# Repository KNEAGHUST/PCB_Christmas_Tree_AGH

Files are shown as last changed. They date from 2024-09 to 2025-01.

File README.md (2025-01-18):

<p align="center">PCB_Christmas_Tree_AGH</p>

<h2>🧐 Features</h2>

So... it's a christmas tree... just made from a PCB!

It is green, has stars on it and... it blinks!

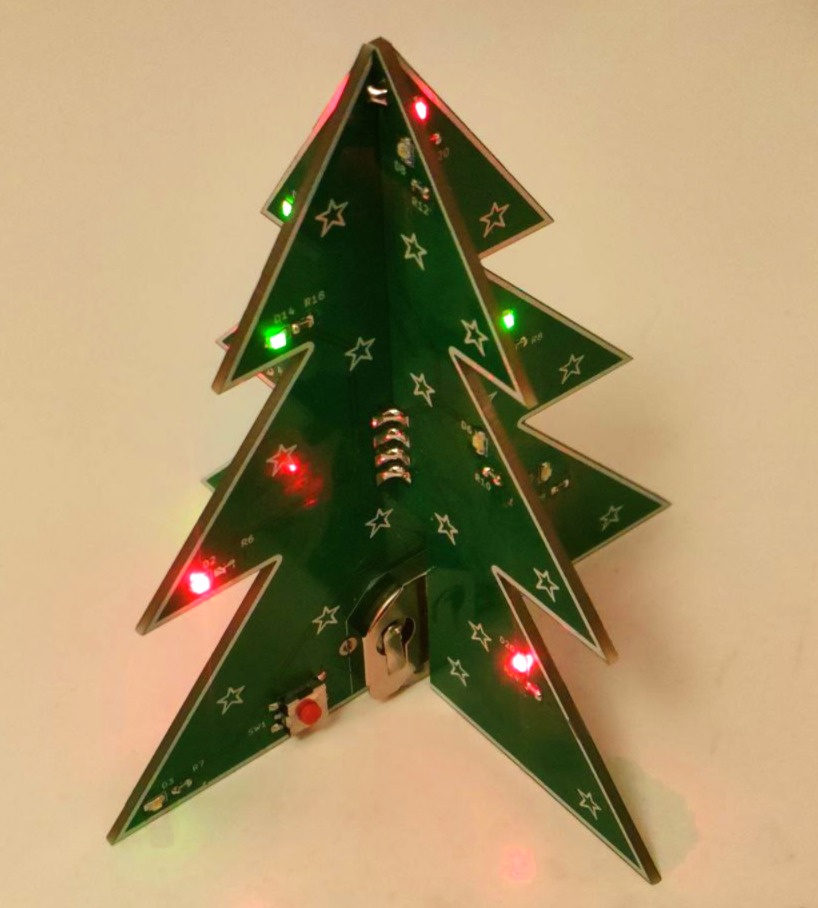
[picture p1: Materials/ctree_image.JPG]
ctree photo


<h2>💾 PCB Design</h2>

The schematics and PCB were designed using KiCAD 7. All the files are available in this repository.

The christmass tree is actually made up of two PCB, that slide into each other and you can solder them toghether.

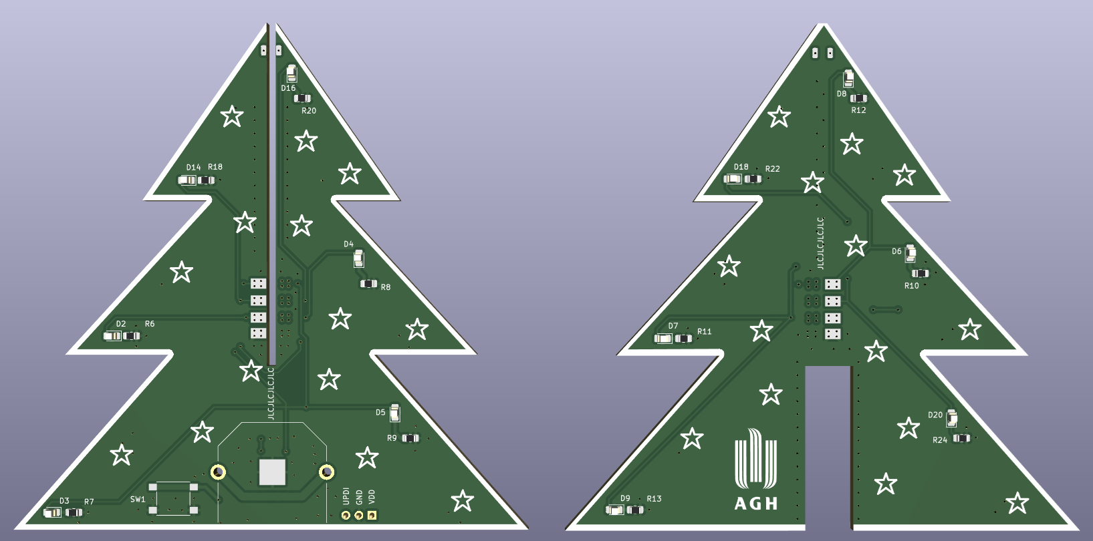
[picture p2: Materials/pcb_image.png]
PCB


<h2>💻 Built with</h2>

Technologies used in the project:

*  Microchips Attiny402 microcontroller
*  0805 LEDs and resistors
*  CR2032 battery
*  6 mm tact switch for changing blink modes

<h2>📖 Documentation and project files </h2>

The CTree submodule contains all the code for the attiny, feel free to create pull requests with your own improvements!

KiCAD files has all the schematics and pcb files you might need, but if you just want to build one without making any changes,
Manufacturing files folder has all the gerber files you will need.

Under Materials you should find the current BOM and any oher useful files.

UPDIProgrammer is a python script used to flash the Attiny microcontrolller.

<h2>🛡️ License:</h2>

This project is licensed under the MIT License.

<h2> 🙋‍♂️Authors </h2>

- Krzysztof Sikora (hardware)
- Marek Pawłowski (firmware)

<h2>💖Like my work?</h2>

If you have any questions about the project feel free to contact us via email: krzysieksikora717@gmail.com

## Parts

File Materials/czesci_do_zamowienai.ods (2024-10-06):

Element | Cena jednostkowa NETTO | Ilość | Cena łącznie | Link TME | NOTATKI
Attiny402 | 1.77 | 500 | 885 | https://www.mouser.pl/ProductDetail/Microchip-Technology/ATTINY402-SSN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 | Cena jednostkowa przy 100 sztukach | MOUSER
MMFTP84W | 0.1074 | 2850 | 306.09 | https://www.tme.eu/pl/details/mmftp84w-dio/tranzystory-z-kanalem-p-smd/diotec-semiconductor/mmftp84w/ | Cena przy 500 sztukach
BC846-QR | 0.0595 | 2000 | 119 | https://www.tme.eu/pl/details/bc846-qr/tranzystory-npn-smd/nexperia/ | Cena przy 250 sztukach
BAS70-5 | 0.098 | 2000 | 196 | https://www.tme.eu/pl/details/bas70-05-dio/diody-schottky-smd/diotec-semiconductor/bas70-5/ | Cena przy 100 sztukach
0603WAJ0103T5E | 0.0025 | 10000 | 25 | https://www.tme.eu/pl/details/smd0603-10k/rezystory-smd/royal-ohm/0603saj0103t5e/ | Cena przy 1000 sztuk
TACTM-64N-F | 0.556 | 1000 | 556 | https://www.tme.eu/pl/details/pts645sk43smtr92/mikroprzelaczniki-tact/c-k/pts645sk43smtr92-lfs/ | Cena przy 1000 sztuk
FYLS-0805URC (czerwone) | 0.0681 | 5000 | 340.5 | https://www.tme.eu/pl/details/rf-rub170ts-bd/diody-led-smd-kolorowe/refond/ | Cena przy 4000 sztukach
LL-S170UYC-Y2-1B (żółte) | 0.0653 | 5000 | 326.5 | https://www.tme.eu/pl/details/ll-s170uyc-y2-1b/diody-led-smd-kolorowe/luckylight/ | Cena przy 1000 sztukach
LTST-C170KFKT (pomarańczowe) | 0.1266 | 5000 | 633 | https://www.tme.eu/pl/details/ltst-c170kfkt/diody-led-smd-kolorowe/liteon/ | Cena przy 1000 sztukach
RF-GSB170TS-BC (żółto-zielone) | 0.0905 | 3890 | 352.045 | https://www.tme.eu/pl/details/rf-gsb170ts-bc/diody-led-smd-kolorowe/refond/ | Cena przy 1000 sztukach
0603SAF1000T5E | 0.00408 | 30000 | 122.4 | https://www.tme.eu/pl/details/0603saf2200t5e/rezystory-smd/royal-ohm/ | Cena przy 5000 sztuk
Koszyk na baterię | 1.936 | 500 | 968 | https://www.tme.eu/pl/details/keys3003/baterie-pojemniki-i-uchwyty/keystone/3003/ | Cena przy 20 sztukach
Bateria CR2032 | 0.634 | 500 | 317 | https://www.tme.eu/pl/details/bat-cr2032_a/baterie/akyga-battery/aky1075/ | Cena przy 100 sztukach
SUMA | 5146.535

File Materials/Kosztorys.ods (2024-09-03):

Element | Cena jednostkowa NETTO | Ilość | Cena łącznie | Link TME | NOTATKI
Attiny402 | 1.778 | 1 | 1.778 | https://www.tme.eu/pl/details/attiny402-ssn/rodzina-avr-8-bit/microchip-technology/ | Cena jednostkowa przy 100 sztukach
MMFTP84W | 0.1074 | 4 | 0.4296 | https://www.tme.eu/pl/details/mmftp84w-dio/tranzystory-z-kanalem-p-smd/diotec-semiconductor/mmftp84w/ | Cena przy 500 sztukach
BC846-QR | 0.0595 | 1 | 0.0595 | https://www.tme.eu/pl/details/bc846-qr/tranzystory-npn-smd/nexperia/ | Cena przy 250 sztukach
BAS70-5 | 0.098 | 1 | 0.098 | https://www.tme.eu/pl/details/bas70-05-dio/diody-schottky-smd/diotec-semiconductor/bas70-5/ | Cena przy 100 sztukach
0603WAJ0103T5E | 0.00711 | 1 | 0.00711 | https://www.tme.eu/pl/details/smd0603-10k/rezystory-smd/royal-ohm/0603saj0103t5e/ | Cena przy 1000 sztuk
0603WAJ0104T5E | 0.00328 | 1 | 0.00328 | https://www.tme.eu/pl/details/0603waj0104t5e/rezystory-smd/royal-ohm/ | Cena przy 5000 sztuk
TACTM-64N-F | 0.697 | 1 | 0.697 | https://www.tme.eu/pl/details/tactm-64n-f/mikroprzelaczniki-tact/ninigi/ | AKTUALNIE BRAK
FYLS-0805URC (czerwone) | 0.1086 | 6 | 0.6516 | https://www.tme.eu/pl/details/fyls-0805urc/diody-led-smd-kolorowe/foryard/ | Cena przy 1000 sztukach
LL-S170UYC-Y2-1B (żółte) | 0.0653 | 6 | 0.3918 | https://www.tme.eu/pl/details/ll-s170uyc-y2-1b/diody-led-smd-kolorowe/luckylight/ | Cena przy 1000 sztukach
LTST-C170KFKT (pomarańczowe) | 0.1368 | 6 | 0.8208 | https://www.tme.eu/pl/details/ltst-c170kfkt/diody-led-smd-kolorowe/liteon/ | Cena przy 1000 sztukach
RF-GSB170TS-BC (żółto-zielone) | 0.0974 | 6 | 0.5844 | https://www.tme.eu/pl/details/rf-gsb170ts-bc/diody-led-smd-kolorowe/refond/ | Cena przy 1000 sztukach
0603SAF1000T5E | 0.00402 | 24 | 0.09648 | https://www.tme.eu/pl/details/0603saf1000t5e/rezystory-smd/royal-ohm/ | Cena przy 5000 sztuk
BC-2002 | 0.73 | 1 | 0.73 | https://www.tme.eu/pl/details/bc-2002/baterie-pojemniki-i-uchwyty/comf/ | Cena przy 1000 sztukach
Bateria CR2032 | 0.634 | 1 | 0.634 | https://www.tme.eu/pl/details/bat-cr2032_a/baterie/akyga-battery/aky1075/ | Cena przy 100 sztukach
SUMA | 6.98157

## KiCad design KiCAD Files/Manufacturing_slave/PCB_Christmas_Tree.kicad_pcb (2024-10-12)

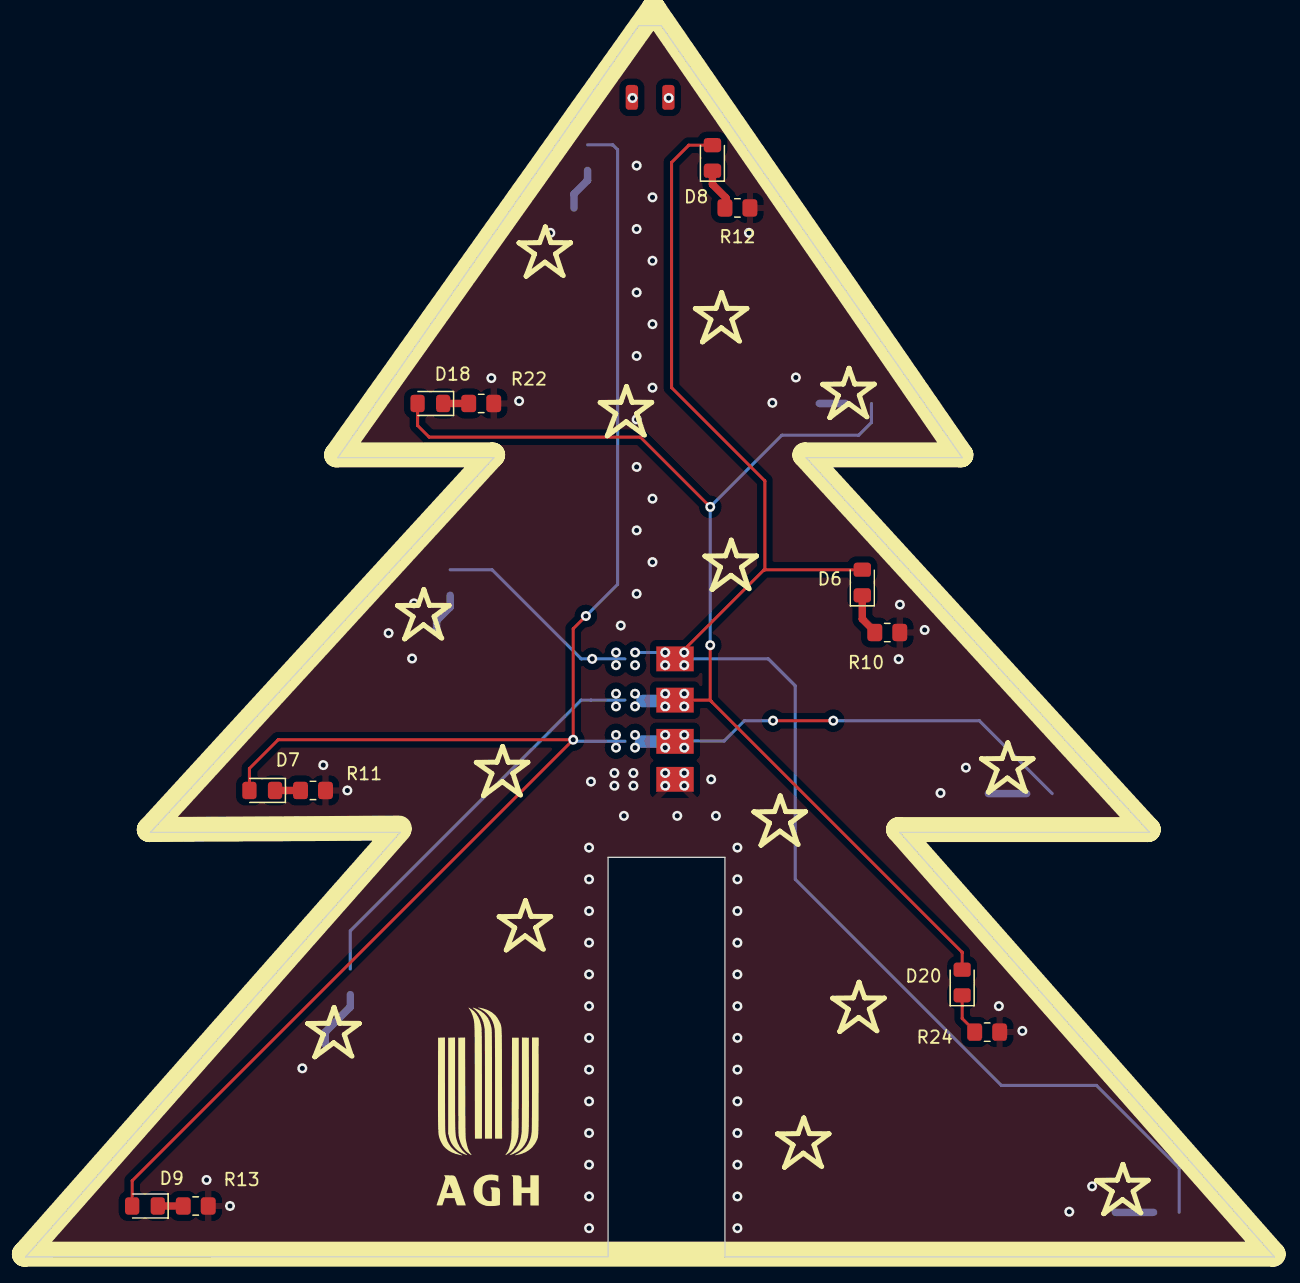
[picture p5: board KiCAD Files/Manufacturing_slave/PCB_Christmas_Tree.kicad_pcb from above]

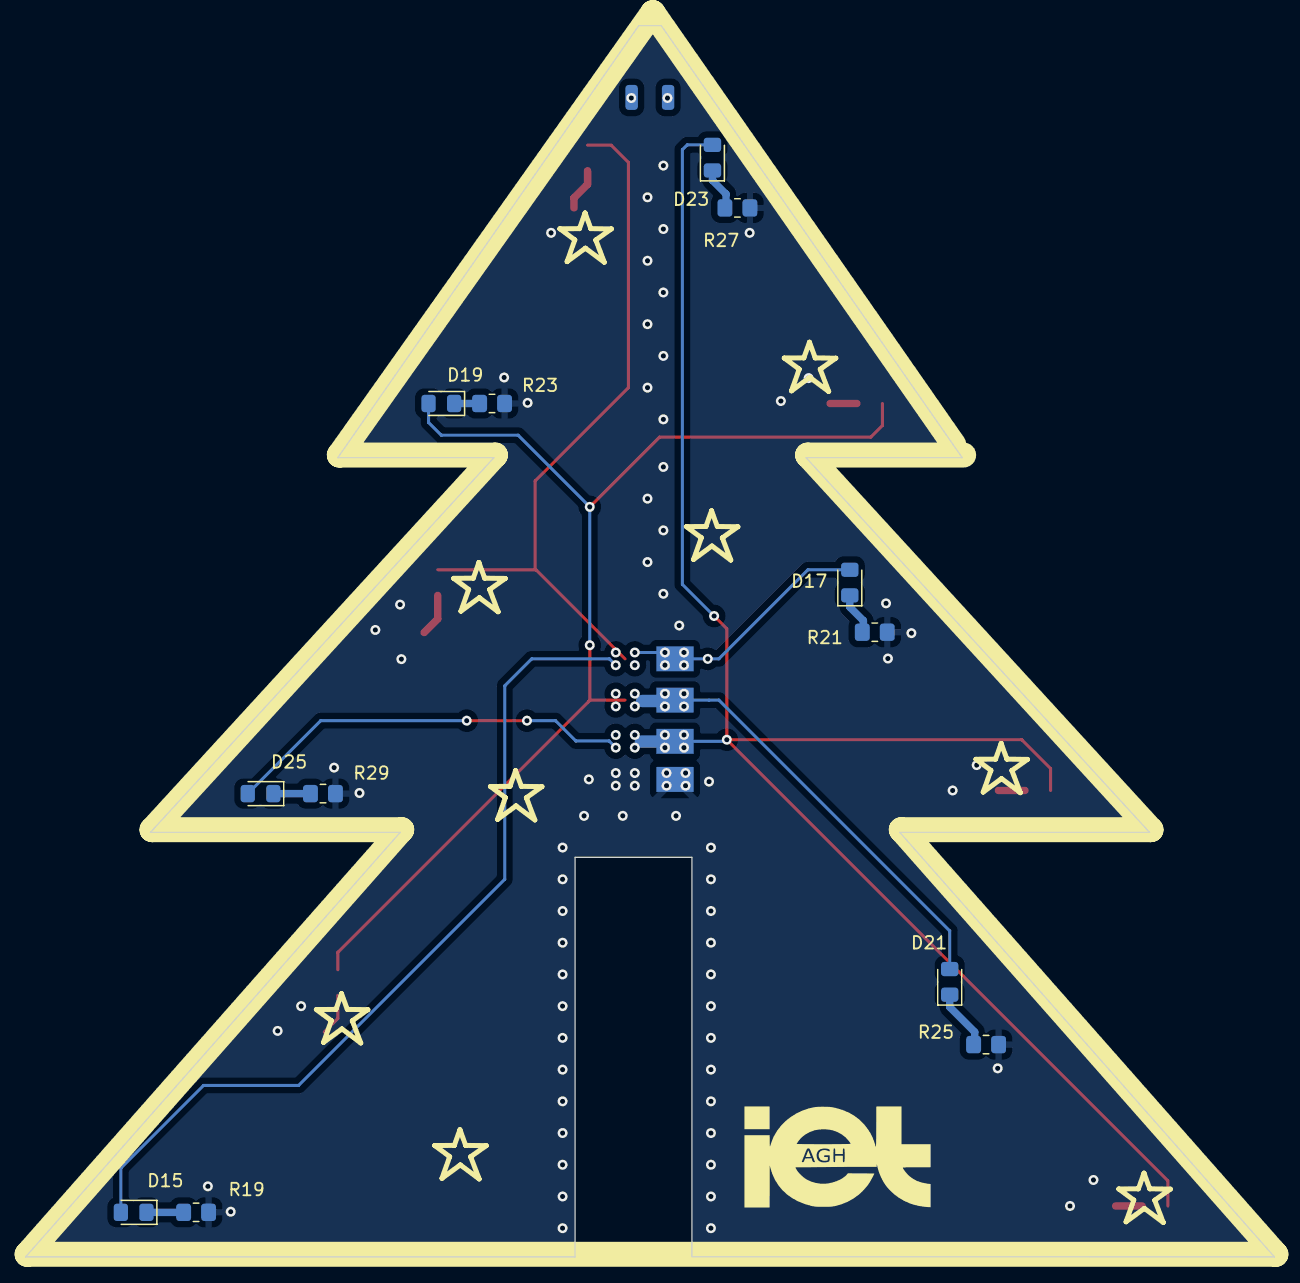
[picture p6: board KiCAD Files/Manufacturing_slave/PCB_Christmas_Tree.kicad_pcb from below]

Board: 2 copper layers, 100.0 x 98.6 mm, 26 parts (13 on the bottom side), 7 nets.

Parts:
D6, D7, D8, D9, D15, D17, D18, D19, D20, D21, D23, D25: LED; LED_0805_2012Metric_Pad1.15x1.40mm_HandSolder
J4, J5: Conn_01x04_Pin; Multi_board_connector
R10, R11, R12, R13, R19, R21, R22, R23, R24, R25, R27, R29: 100; R_0805_2012Metric_Pad1.20x1.40mm_HandSolder

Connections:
/LED_Power_1: D6.2 (A), D8.2 (A), D15.2 (A), D17.2 (A), J4.1, J5.1
/LED_Power_2: D18.2 (A), D19.2 (A), D20.2 (A), D21.2 (A), J4.2, J5.2
/LED_Power_3: D7.2 (A), D9.2 (A), D23.2 (A), D25.2 (A), J4.3, J5.3
GND: J4.4, J5.4, R10.2, R11.2, R12.2, R13.2, R19.2, R21.2, R22.2, R23.2, R24.2, R25.2, R27.2, R29.2
unnamed: D15.1 (K), R19.1
unnamed: D17.1 (K), R21.1
unnamed: D20.1 (K), R24.1

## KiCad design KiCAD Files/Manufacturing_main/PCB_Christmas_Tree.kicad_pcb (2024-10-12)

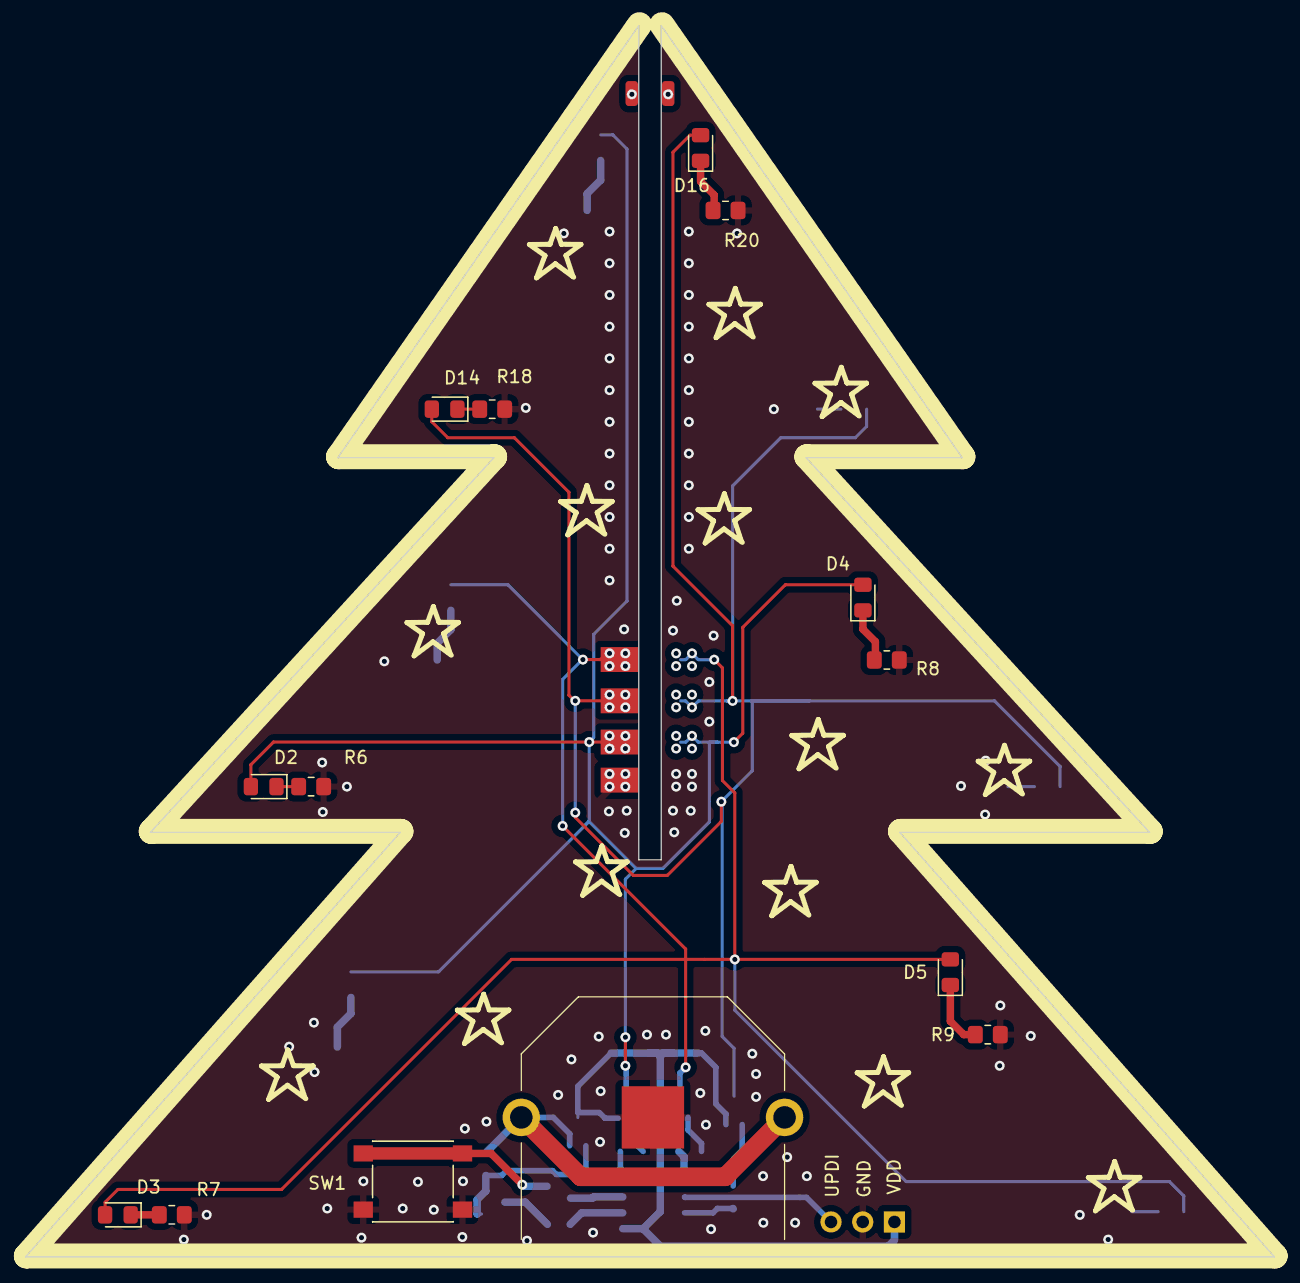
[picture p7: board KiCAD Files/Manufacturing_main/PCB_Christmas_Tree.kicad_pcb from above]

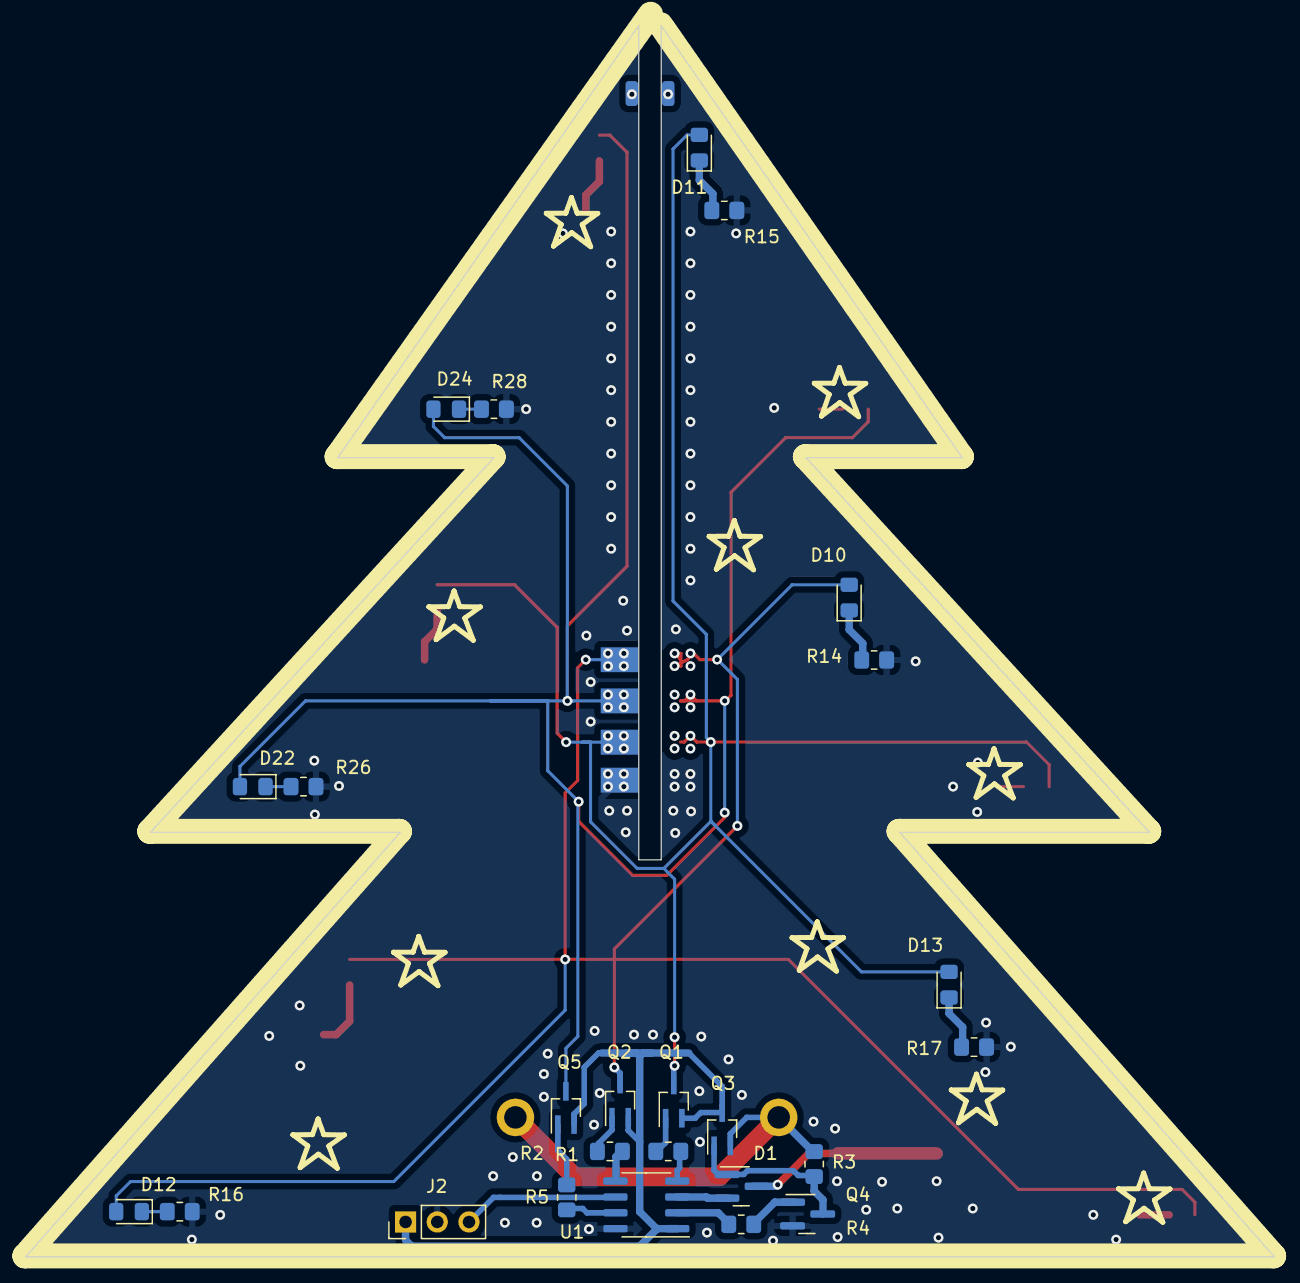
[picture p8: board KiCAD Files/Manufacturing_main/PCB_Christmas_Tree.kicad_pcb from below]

Board: 2 copper layers, 100.0 x 98.6 mm, 41 parts (26 on the bottom side), 21 nets.

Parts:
D1: D_Schottky_Dual_CommonCathode_AAK; SOT-23
D2, D3, D4, D5, D10, D11, D12, D13, D14, D16, D22, D24: LED; LED_0805_2012Metric_Pad1.15x1.40mm_HandSolder
J1: CR2032; BC-2002
J2: Conn_01x03_Pin; PinHeader_1x03_P2.54mm_Vertical
J3, J6: Conn_01x04_Pin; Multi_board_connector
Q1, Q2, Q3, Q5: AO3401A; SOT-323_SC-70_Handsoldering
Q4: BC817; SOT-23
R1, R2, R3, R4, R5: 10k; R_0805_2012Metric_Pad1.20x1.40mm_HandSolder
R6, R7, R8, R9, R14, R15, R16, R17, R18, R20, R26, R28: 100; R_0805_2012Metric_Pad1.20x1.40mm_HandSolder
SW1: SW_Omron_B3FS; SW_Push_1P1T_NO_6x6mm_H9.5mm
U1: ATtiny402-SS; SOIC-8_3.9x4.9mm_P1.27mm

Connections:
+BATT: J1.1, Q3.2 (S), R3.1
/LED_Power_1: D3.2 (A), D5.2 (A), D10.2 (A), D12.2 (A), J3.1, J6.1, Q2.3 (D)
/LED_Power_2: D14.2 (A), D16.2 (A), D22.2 (A), D24.2 (A), J3.2, J6.2, Q5.3 (D)
/LED_Power_3: D2.2 (A), D4.2 (A), D11.2 (A), D13.2 (A), J3.3, J6.3, Q1.3 (D)
/LED_Set_1: R2.1, U1.5 (PA2)
/LED_Set_2: R5.1, U1.7 (PA3)
/LED_Set_3: R1.1, U1.4 (PA1)
/Power_sustain: R4.2, U1.2 (PA6)
/Switch_in: D1.2 (A), U1.3 (PA7)
/UDPI: J2.3, U1.6 (~RESET/PA0)
GND: J1.2, J2.2, J3.4, J6.4, Q4.2 (E), R6.2, R7.2, R8.2, R9.2, R14.2, R15.2, R16.2, R17.2, R18.2, R20.2, R26.2, R28.2, SW1.1, U1.8 (GND)
unnamed: D1.3 (K), SW1.2
unnamed: D10.1 (K), R14.1
unnamed: D12.1 (K), R16.1
unnamed: D22.1 (K), R26.1
unnamed: Q1.1 (G), R1.2
unnamed: Q2.1 (G), R2.2
unnamed: D1.1 (A), Q3.1 (G), Q4.3 (C), R3.2
unnamed: Q4.1 (B), R4.1
unnamed: Q5.1 (G), R5.2
VDD: J2.1, Q1.2 (S), Q2.2 (S), Q3.3 (D), Q5.2 (S), U1.1 (VCC)

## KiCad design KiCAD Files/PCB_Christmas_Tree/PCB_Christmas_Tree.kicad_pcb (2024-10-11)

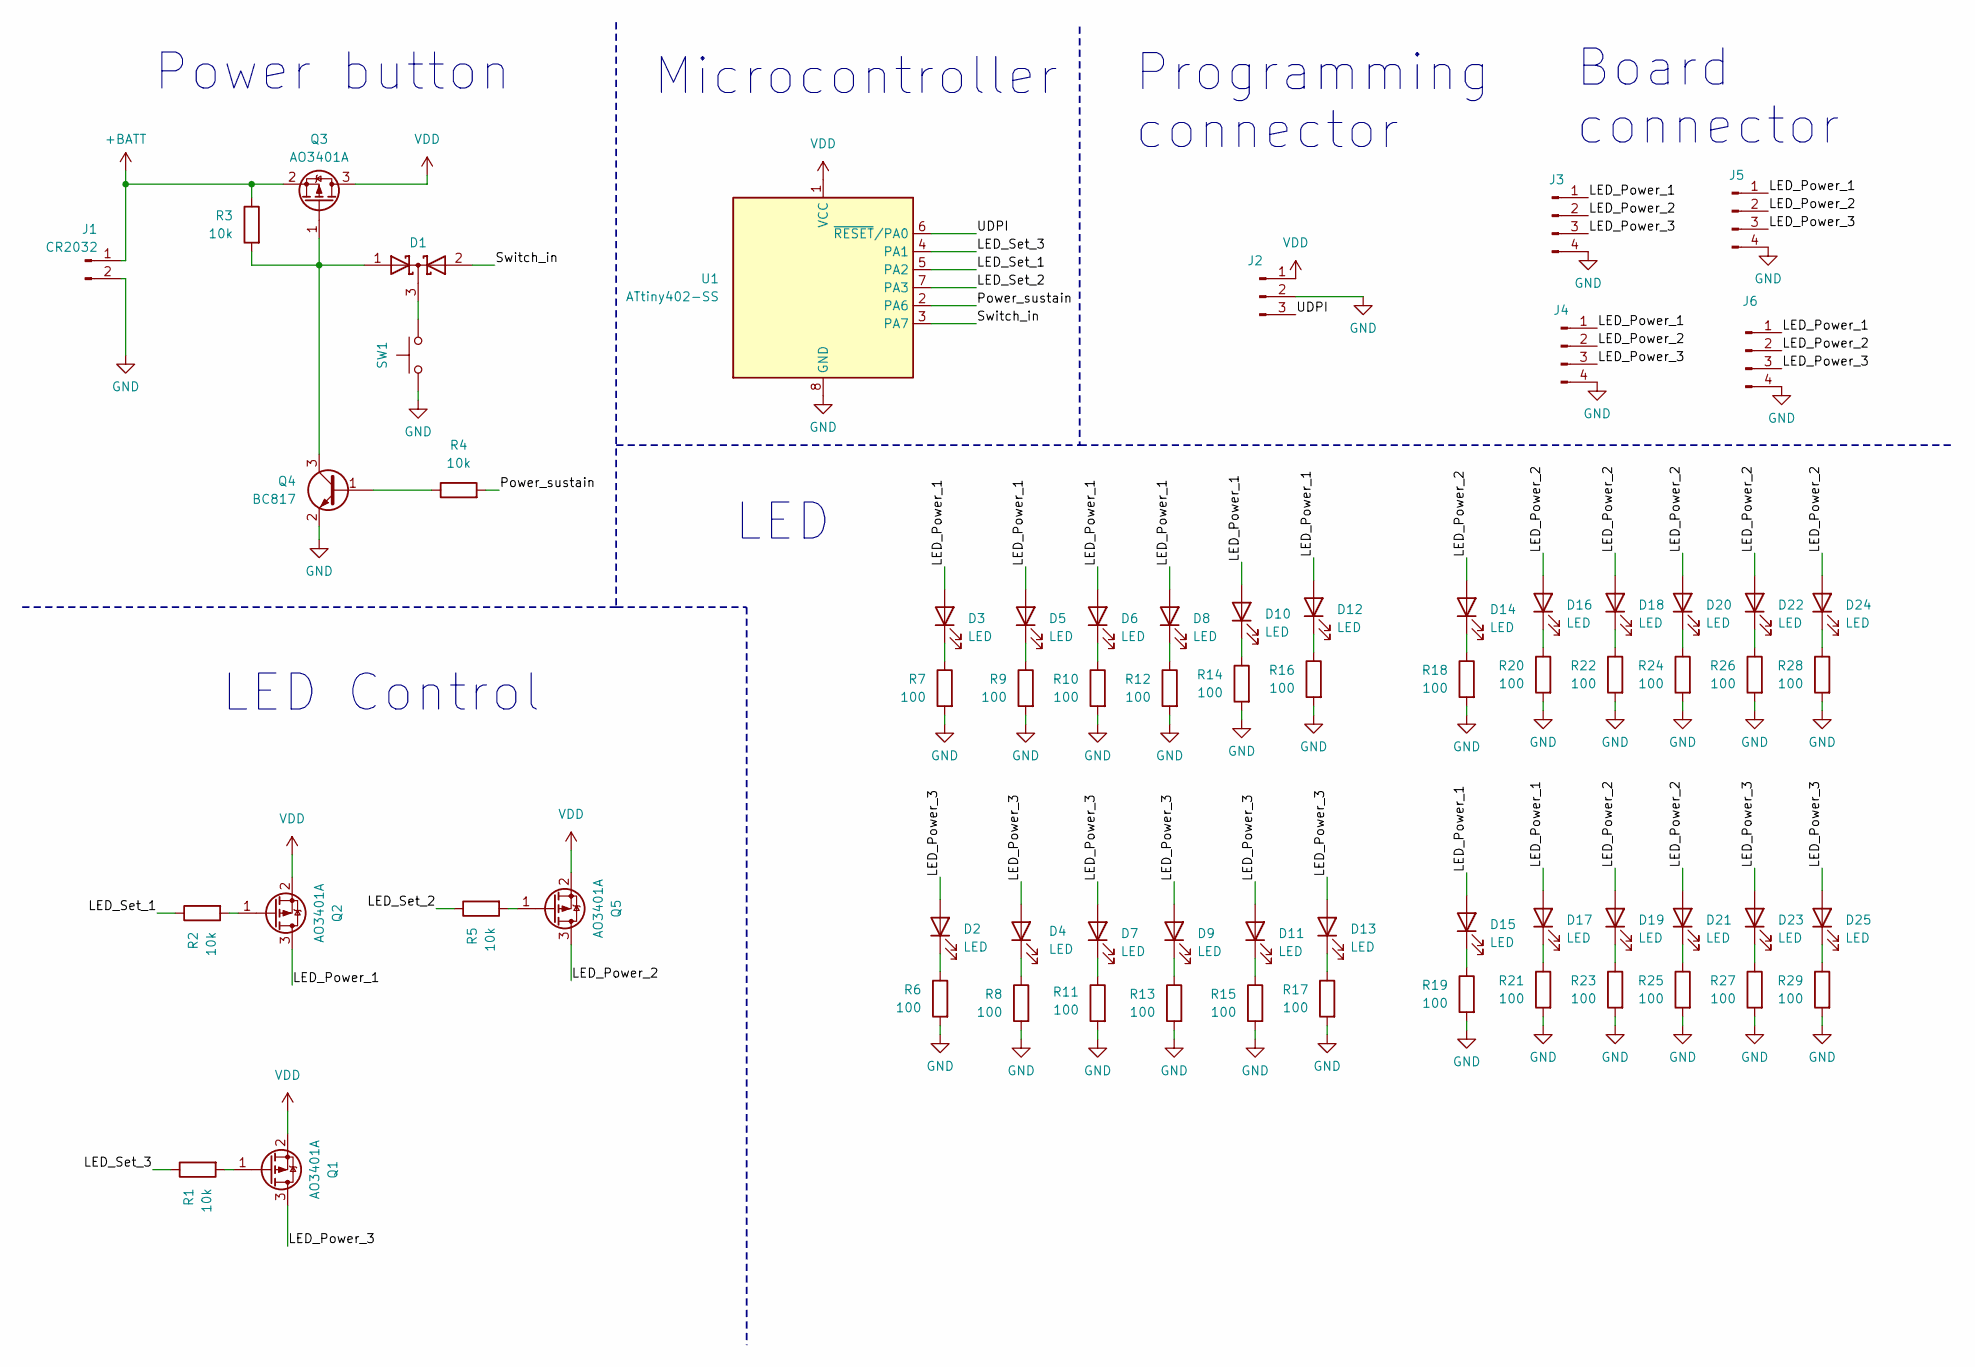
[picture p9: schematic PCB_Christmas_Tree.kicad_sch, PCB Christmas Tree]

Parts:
D1: D_Schottky_Dual_CommonCathode_AAK; SOT-23
D2, D3, D4, D5, D6, D7, D8, D9, D10, D11, D12, D13, D14, D15, D16, D17, D18, D19, D20, D21, D22, D23, D24, D25: LED; LED_0805_2012Metric_Pad1.15x1.40mm_HandSolder
J1: CR2032; BC-2002
J2: Conn_01x03_Pin; PinHeader_1x03_P2.54mm_Vertical
J3, J4, J5, J6: Conn_01x04_Pin; Multi_board_connector
Q1, Q2, Q3, Q5: AO3401A; SOT-323_SC-70_Handsoldering
Q4: BC817; SOT-23
R1, R2, R3, R4, R5: 10k; R_0805_2012Metric_Pad1.20x1.40mm_HandSolder
R6, R7, R8, R9, R10, R11, R12, R13, R14, R15, R16, R17, R18, R19, R20, R21, R22, R23, R24, R25, R26, R27, R28, R29: 100; R_0805_2012Metric_Pad1.20x1.40mm_HandSolder
SW1: SW_Omron_B3FS; SW_Push_1P1T_NO_6x6mm_H9.5mm
U1: ATtiny402-SS; SOIC-8_3.9x4.9mm_P1.27mm

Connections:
+BATT: J1.1, Q3.2 (S), R3.1
/LED_Power_1: D3.2 (A), D5.2 (A), D6.2 (A), D8.2 (A), D10.2 (A), D12.2 (A), D15.2 (A), D17.2 (A), J3.1, J4.1, J5.1, J6.1, Q2.3 (D)
/LED_Power_2: D14.2 (A), D16.2 (A), D18.2 (A), D19.2 (A), D20.2 (A), D21.2 (A), D22.2 (A), D24.2 (A), J3.2, J4.2, J5.2, J6.2, Q5.3 (D)
/LED_Power_3: D2.2 (A), D4.2 (A), D7.2 (A), D9.2 (A), D11.2 (A), D13.2 (A), D23.2 (A), D25.2 (A), J3.3, J4.3, J5.3, J6.3, Q1.3 (D)
/LED_Set_1: R2.1, U1.5 (PA2)
/LED_Set_2: R5.1, U1.7 (PA3)
/LED_Set_3: R1.1, U1.4 (PA1)
/Power_sustain: R4.2, U1.2 (PA6)
/Switch_in: D1.2 (A), U1.3 (PA7)
/UDPI: J2.3, U1.6 (~RESET/PA0)
GND: J1.2, J2.2, J3.4, J4.4, J5.4, J6.4, Q4.2 (E), R6.2, R7.2, R8.2, R9.2, R10.2, R11.2, R12.2, R13.2, R14.2, R15.2, R16.2, R17.2, R18.2, R19.2, R20.2, R21.2, R22.2, R23.2, R24.2, R25.2, R26.2, R27.2, R28.2, R29.2, SW1.1, U1.8 (GND)
unnamed: D1.3 (K), SW1.2
unnamed: D2.1 (K), R6.1
unnamed: D3.1 (K), R7.1
unnamed: D4.1 (K), R8.1
unnamed: D5.1 (K), R9.1
unnamed: D6.1 (K), R10.1
unnamed: D7.1 (K), R11.1
unnamed: D8.1 (K), R12.1
unnamed: D9.1 (K), R13.1
unnamed: D10.1 (K), R14.1
unnamed: D11.1 (K), R15.1
unnamed: D12.1 (K), R16.1
unnamed: D13.1 (K), R17.1
unnamed: D14.1 (K), R18.1
unnamed: D15.1 (K), R19.1
unnamed: D16.1 (K), R20.1
unnamed: D17.1 (K), R21.1
unnamed: D18.1 (K), R22.1
unnamed: D19.1 (K), R23.1
unnamed: D20.1 (K), R24.1
unnamed: D21.1 (K), R25.1
unnamed: D22.1 (K), R26.1
unnamed: D23.1 (K), R27.1
unnamed: D24.1 (K), R28.1
unnamed: D25.1 (K), R29.1
unnamed: Q1.1 (G), R1.2
unnamed: Q2.1 (G), R2.2
unnamed: D1.1 (A), Q3.1 (G), Q4.3 (C), R3.2
unnamed: Q4.1 (B), R4.1
unnamed: Q5.1 (G), R5.2
VDD: J2.1, Q1.2 (S), Q2.2 (S), Q3.3 (D), Q5.2 (S), U1.1 (VCC)

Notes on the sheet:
LED
Board connector
LED Control
Power button
Microcontroller
Programming connector

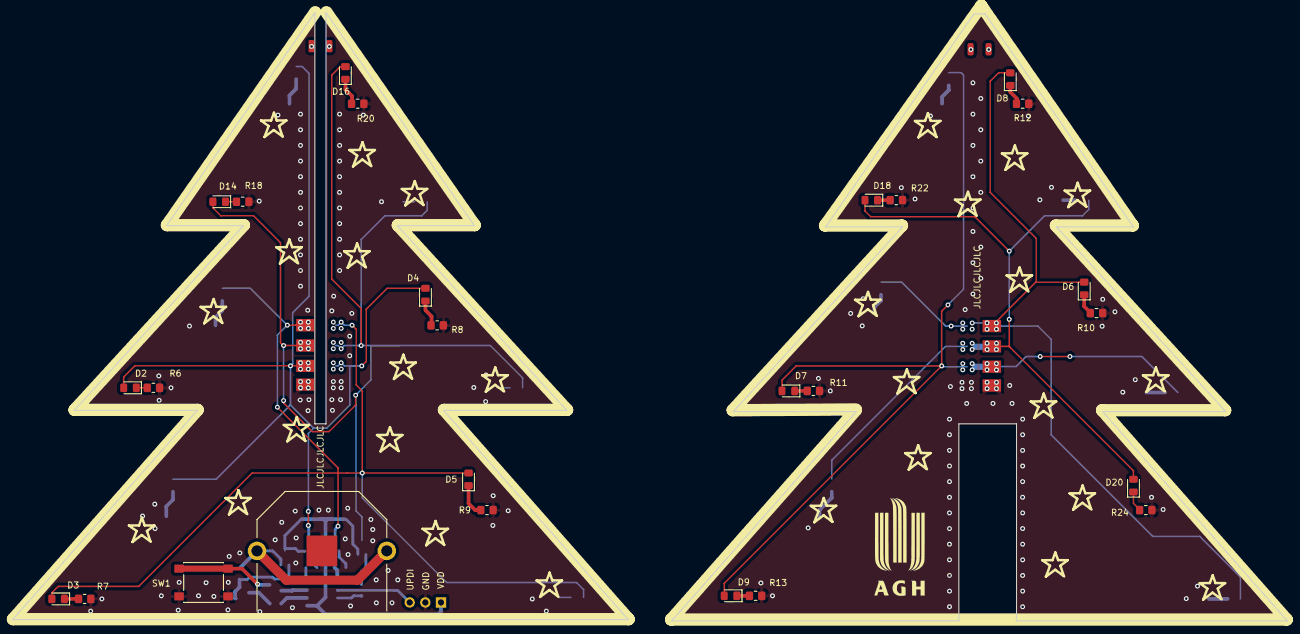
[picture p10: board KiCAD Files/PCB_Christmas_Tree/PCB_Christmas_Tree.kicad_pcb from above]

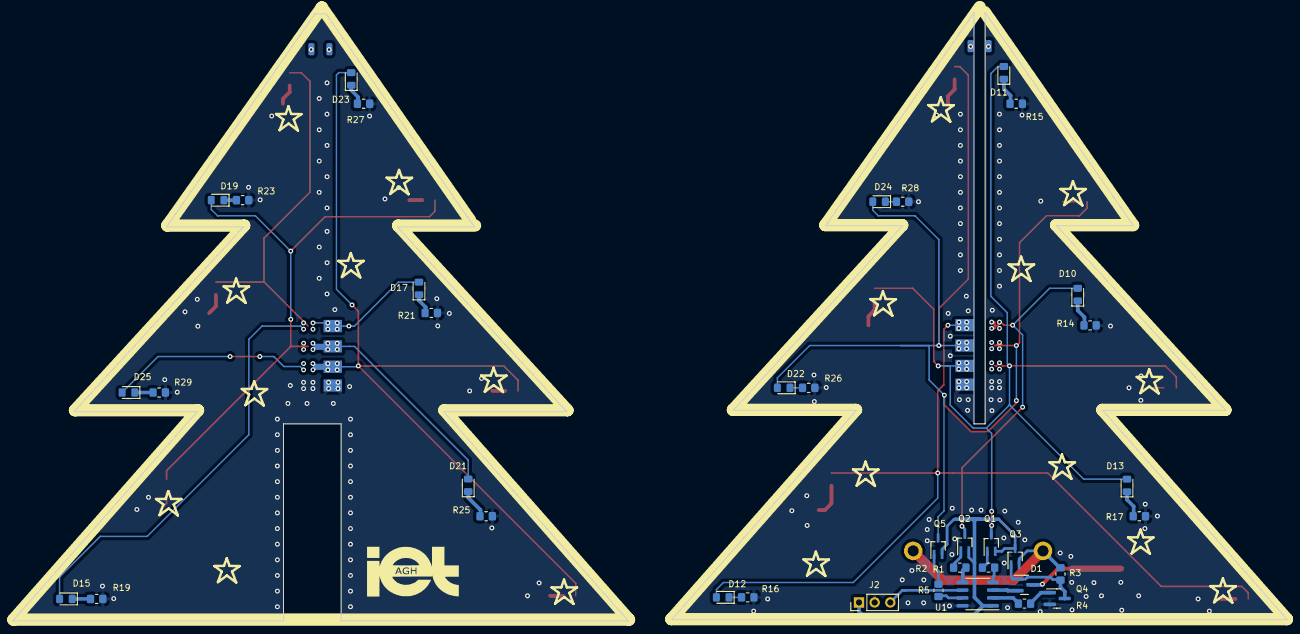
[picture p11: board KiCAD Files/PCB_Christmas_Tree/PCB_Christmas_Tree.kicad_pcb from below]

Board: 2 copper layers, 207.1 x 98.8 mm, 67 parts (39 on the bottom side), 42 nets.

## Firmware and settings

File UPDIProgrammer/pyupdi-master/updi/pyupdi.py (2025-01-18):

#!/usr/bin/env python3
"""
    Simple command line pyupdi utility
"""
import sys
import argparse
import re
import logging

#import device
from device.device import Device
from updi.nvm import UpdiNvmProgrammer
"""
Copyright (c) 2016 Atmel Corporation, a wholly owned subsidiary of Microchip Technology Inc.

Licensed under the Apache License, Version 2.0 (the "License");
you may not use this file except in compliance with the License.
You may obtain a copy of the License at

http://www.apache.org/licenses/LICENSE-2.0

Unless required by applicable law or agreed to in writing, software
distributed under the License is distributed on an "AS IS" BASIS,
WITHOUT WARRANTIES OR CONDITIONS OF ANY KIND, either express or implied.
See the License for the specific language governing permissions and
limitations under the License.
"""

"""
pyupdi is a Python utility for programming AVR devices with UPDI interface
  using a standard TTL serial port.

  Connect RX and TX together with a suitable resistor and connect this node
  to the UPDI pin of the AVR device.

  Be sure to connect a common ground, and use a TTL serial adapter running at
   the same voltage as the AVR device.

                        Vcc                     Vcc
                        +-+                     +-+
                         |                       |
 +---------------------+ |                       | +--------------------+
 | Serial port         +-+                       +-+  AVR device        |
 |                     |      +----------+         |                    |
 |                  TX +------+   4k7    +---------+ UPDI               |
 |                     |      +----------+    |    |                    |
 |                     |                      |    |                    |
 |                  RX +----------------------+    |                    |
 |                     |                           |                    |
 |                     +--+                     +--+                    |
 +---------------------+  |                     |  +--------------------+
                         +-+                   +-+
                         GND                   GND

"""


def _main():
    if sys.version_info[0] < 3:
        print("WARNING: for best results use Python3")

    parser = argparse.ArgumentParser(description="Simple command line"
                                     " interface for UPDI programming")
    parser.add_argument("-d", "--device", choices=Device.get_supported_devices(),
                        required=True, help="Target device")
    parser.add_argument("-c", "--comport", required=True,
                        help="Com port to use (Windows: COMx | *nix: /dev/ttyX)")
    parser.add_argument("-e", "--erase", action="store_true",
                        help="Perform a chip erase (implied with --flash)")
    parser.add_argument("-b", "--baudrate", type=int, default=115200)
    parser.add_argument("-f", "--flash", help="Intel HEX file to flash.")
    parser.add_argument("-r", "--reset", action="store_true",
                        help="Reset")
    parser.add_argument("-i", "--info", action="store_true",
                        help="Info")
    parser.add_argument("-fs", "--fuses", action="append", nargs="*",
                        help="Fuse to set (syntax: fuse_nr:0xvalue)")
    parser.add_argument("-fr", "--readfuses", action="store_true",
                        help="Read out the fuse-bits")
    parser.add_argument("-fe", "--eeprom",
                        help="Intel HEX file to write to EEPROM.")
    parser.add_argument("-v", "--verbose", action="store_true",
                        help="Set verbose mode")

    args = parser.parse_args(sys.argv[1:])

    if not any( (args.fuses, args.flash, args.erase, args.reset, args.readfuses, args.info, args.eeprom) ):
        print("No action (erase, flash, eeprom, reset, fuses or info)")
        sys.exit(0)

    if args.verbose:
        logging.basicConfig(format="%(levelname)s:%(name)s %(message)s",
                            level=logging.INFO)
    else:
        logging.basicConfig(format="%(levelname)s:%(name)s %(message)s",
                            level=logging.WARNING)

    nvm = UpdiNvmProgrammer(comport=args.comport,
                            baud=args.baudrate,
                            device=Device(args.device))
    if not args.reset: # any action except reset
        # Reteieve info before building the stack to be sure its the correct device
        nvm.get_device_info()
        try:
            nvm.enter_progmode()
        except:
            print("Device is locked. Performing unlock with chip erase.")
            nvm.unlock_device()

        print("Device info: {0:s}".format(str(nvm.get_device_info())))

        if not _process(nvm, args):
            print("Error during processing")

    # Reset only needs this.
    nvm.leave_progmode()


def _process(nvm, args):
    if args.erase:
        try:
            nvm.chip_erase()
        except:
            return False
    if args.fuses is not None:
        for fslist in args.fuses:
            for fsarg in fslist:
                if not re.match("^[0-9]+:0x[0-9a-fA-F]+$", fsarg):
                    print("Bad fuses format {}. Expected fuse_nr:0xvalue".format(fsarg))
                    continue
                lst = fsarg.split(":0x")
                fusenum = int(lst[0])
                value = int(lst[1], 16)
                if not _set_fuse(nvm, fusenum, value):
                    return False
    if args.flash is not None:
        return _flash_file(nvm, args.flash)
    if args.eeprom is not None:
        return _write_eeprom(nvm, args.eeprom)
    if args.readfuses:
        if not _read_fuses(nvm):
            return False
    return True


def _flash_file(nvm, filename):
    data, start_address = nvm.load_ihex_flash(filename)

    fail = False

    nvm.chip_erase()
    nvm.write_flash(start_address, data)

    # Read out again
    readback = nvm.read_flash(start_address, len(data))
    for i, _ in enumerate(data):
        if data[i] != readback[i]:
            print("Verify error at location 0x{0:04X}: expected 0x{1:02X} read 0x{2:02X} ".format(i, data[i],
                                                                                                  readback[i]))
            fail = True

    if not fail:
        print("Programming successful")
    return not fail


def _set_fuse(nvm, fusenum, value):
    nvm.write_fuse(fusenum, value)
    actual_val = nvm.read_fuse(fusenum)
    ret = actual_val == value
    if not ret:
        print("Verify error for fuse {0}, expected 0x{1:02X} read 0x{2:02X}".format(fusenum, value, actual_val))
    else:
        print("Fuse {0} set to 0x{1:02X} successfully".format(fusenum, value))
    return ret


def _read_fuses(nvm):
    print("Fuse:Value")
    for fusenum in range (0,11): # This range should probably be defined for each chip
        fuseval=nvm.read_fuse(fusenum)
        print("{0}:0x{1:02X}".format(fusenum,fuseval))
    return True


def _write_eeprom(nvm, filename):
    data, start_address = nvm.load_ihex_eeprom(filename)

    fail = False

    nvm.eeprom_erase()
    nvm.write_eeprom(start_address, data)

    # Read out again
    readback = nvm.read_eeprom(nvm.device.eeprom_start, len(data))
    for i, _ in enumerate(data):
        if data[i] != readback[i]:
            print("Verify error at location 0x{0:04X}: expected 0x{1:02X} read 0x{2:02X} ".format(i, data[i],
                                                                                                  readback[i]))
            fail = True

    if not fail:
        print("EEPROM write successful")
    return not fail


if __name__ == "__main__":
    _main()

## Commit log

2024-03-09 first BOM
    [Kosztorys.ods]
2024-03-09 KiCAD project
    [Kosztorys.ods, PCB_Christmas_Tree.kicad_pcb, PCB_Christmas_Tree.kicad_sch]
2024-03-09 schematic revision
    [Kosztorys.ods, PCB_Christmas_Tree.kicad_pcb, PCB_Christmas_Tree.kicad_sch]
2024-03-10 pcb revision
    [PCB_Christmas_Tree.kicad_pcb, PCB_Christmas_Tree.kicad_sch]
2024-03-10 pcb update
    [PCB_Christmas_Tree.kicad_pcb]
2024-03-10 kicad preparation for production
    [PCB_Christmas_Tree.kicad_pcb, PCB_Christmas_Tree.kicad_sch]
2024-03-10 gerbers v1
    [PCB_Christmas_Tree-B_Cu.gbl, PCB_Christmas_Tree-B_Mask.gbs, PCB_Christmas_Tree-B_Paste.gbp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]
2024-05-26 schematic update, footprint revision
    [PCB_Christmas_Tree.kicad_pcb, PCB_Christmas_Tree.kicad_sch]
2024-05-26 pcb updates
    [PCB_Christmas_Tree.kicad_pcb]
2024-05-27 pcb modifications
    [PCB_Christmas_Tree.kicad_pcb]
2024-06-18 v2 added
    [PCB_Christmas_Tree-B_Cu.gbl, PCB_Christmas_Tree-B_Mask.gbs, PCB_Christmas_Tree-B_Paste.gbp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]
2024-10-06 kosztorys update
    [Kosztorys.xlsx, czesci_do_zamowienai.ods]
2024-10-06 dodano przelotki
    [PCB_Christmas_Tree.kicad_pcb]
2024-10-08 zmiana pinoutu zlacza UPDI
    [PCB_Christmas_Tree.kicad_pcb, PCB_Christmas_Tree.kicad_sch]
2024-10-11 Dodano pliki gerber v1
    [PCB_Christmas_Tree-B_Cu.gbl, PCB_Christmas_Tree-B_Mask.gbs, PCB_Christmas_Tree-B_Paste.gbp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]
2024-10-12 dodano gerbery bez napisu JLCJLCJLC
    [PCB_Christmas_Tree-B_Cu.gbl, PCB_Christmas_Tree-B_Mask.gbs, PCB_Christmas_Tree-B_Paste.gbp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]
2024-11-13 dodano skrypt do programowania poprzez UPDI
    [PCB_Christmas_Tree.kicad_pcb_bez_logo_AGH-B_Cu.gbl, PCB_Christmas_Tree.kicad_pcb_bez_logo_AGH-B_Mask.gbs, PCB_Christmas_Tree.kicad_pcb_bez_logo_AGH-B_Paste.gbp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]
